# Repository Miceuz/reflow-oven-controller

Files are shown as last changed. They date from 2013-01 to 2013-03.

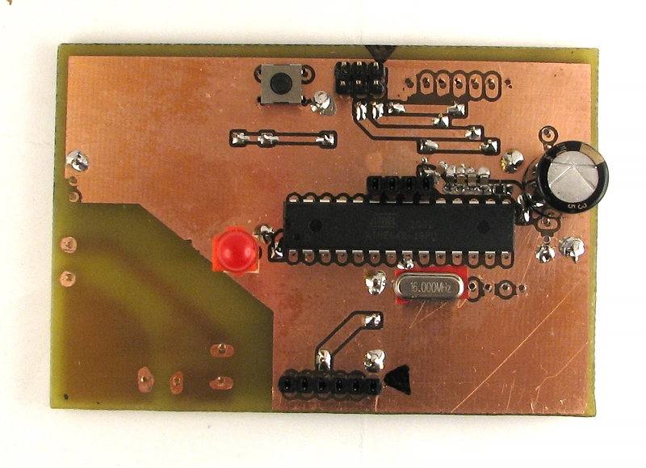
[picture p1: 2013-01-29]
pics/top.jpg

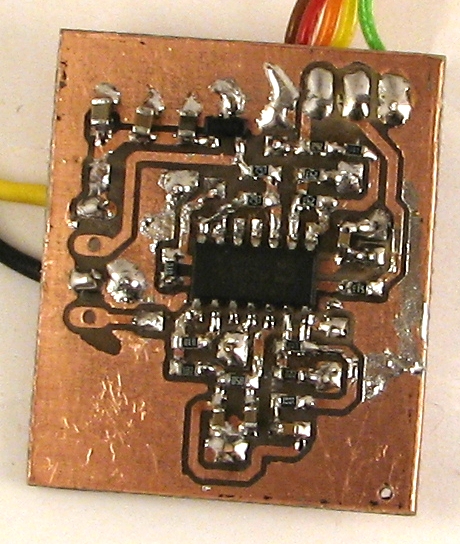
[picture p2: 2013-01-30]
pics/pt100-daughterboard.jpg

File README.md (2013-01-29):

reflow-oven-controller
======================

Yet another reflow oven controller (YAROC, but we called it c-flow) for [c-base](http://c-base.org). The design is mainly based on parts we had available in c-lab. *Note: the project is work in progress, major fuckups may be present in the design files*

The design is modular:
- MCU board has a microcontroller, a solid state relay and a header for analog temperature sensor daughterboards. Headers for ISP programming, SPI communication and CP2102 USB-to-USART module are available too. SSR used is S102S02.
- a daughterboard for PT100 sensor has all the analog sensor conditioning circuitry: constant current source, wire resistance elimination, active filter. Based on Microchip App Note [AN687](http://www.microchip.com/stellent/idcplg?IdcService=SS_GET_PAGE&nodeId=1824&appnote=en011700)
- Arduino compatible

UI features available
---------------------

- power LED
- "heater on" LED
- "oven running" LED
- "start/stop" button
- SPI header for serial LCD module
- I2C header
- 4 AUX IOs with pullup and pulldown pads

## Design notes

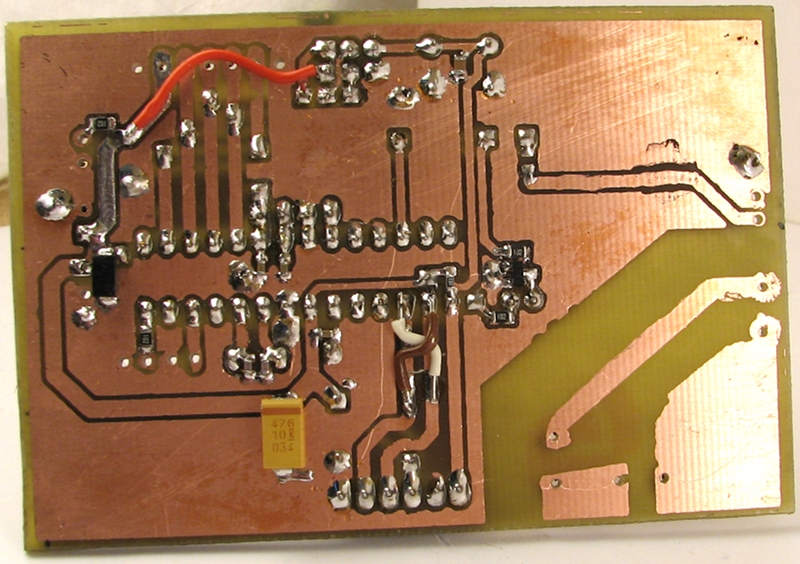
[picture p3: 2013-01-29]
pics/bottom.jpg

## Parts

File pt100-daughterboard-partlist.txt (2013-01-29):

Partlist

Exported from pt100-daughterboard.brd at 2013/01/23/ 4:52 PM

EAGLE Version 5.11.0 Copyright (c) 1988-2010 CadSoft

Part         Value          Package       Library       Position (mm)         Orientation

C1           390nF          C0603         adafruit      (14.605 26.9875)      R90
C2           68nf           C0603         adafruit      (9.525 27.6225)       R180
C3           180nF          C0603         adafruit      (12.3825 26.9875)     R90
C4           10uF           C0805         adafruit      (24.13 6.35)          R270
C5           100nF          C0603         adafruit      (6.35 14.2875)        R270
IC1          LM324D         SO14          linear        (12.7 16.8275)        R0
IC2          REF31XX        DBZ_R-PDSO-G3 mic-misc      (15.24 6.6675)        R180
JP1                         1X03_LONGPADS SparkFun      (3.81 4.1275)         MR180
R1           25K            0603          microbuilder  (8.89 9.8425)         R180
R2           25K            0603          microbuilder  (8.89 11.7475)        R0
R3           25K            0603          microbuilder  (12.7 11.7475)        R180
R4           25K            0603          microbuilder  (12.7 9.8425)         R0
R5           2.5K           0603          microbuilder  (8.89 7.9375)         R180
R6           100K           0603          microbuilder  (18.7325 16.8275)     R270
R7           100K           0603          microbuilder  (16.8275 21.9075)     R180
R9           49.9K          0603          microbuilder  (5.08 17.4625)        R180
R10          17.4K          0603          microbuilder  (16.8275 23.8125)     R0
R11          107K           0603          microbuilder  (13.335 24.4475)      R0
R12          1K             0603          microbuilder  (9.525 25.7175)       R0
R13          3.09K          0603          microbuilder  (9.525 23.8125)       R180
R14          20K            0603          microbuilder  (9.525 21.9075)       R0
SENSOR_BOARD                04P           con-amp-quick (24.13 16.8275)       MR270

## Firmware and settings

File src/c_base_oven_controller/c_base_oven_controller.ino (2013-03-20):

#include <Cmd.h>

#define HEATER A3
#define RUN_LED 8
#define BUTTON 6

#define PRESSED 1
#define MAYBE_PRESSED 2
#define RELEASED 3
#define MAYBE_RELEASED 4

typedef struct {
  byte temperature;
  byte holdSeconds;
} tProgramPoint;

const int tempInput = A0;
boolean heaterOn = false;
boolean running = false;

unsigned long lastPrint = 0;
unsigned long lastDebounce = 0;
byte buttonState = RELEASED;
byte lastButtonState = RELEASED;
//byte setTemperature = 235;
unsigned int tempMaxHold = 30000;
byte tempReached = false;
unsigned long tempReachedTimestamp = 0;

tProgramPoint program[]={
  {150, 180},
  {205, 15},
  {0, 0}
};

byte programStep = 0;


void blinkHello() {
  byte i;
  for(i = 0; i < 10; i++) {
    digitalWrite(RUN_LED, !digitalRead(RUN_LED));
    delay(100);
  }
}

void setup() {
  pinMode(RUN_LED, OUTPUT);
  pinMode(HEATER, OUTPUT);
  pinMode(BUTTON, INPUT);
  digitalWrite(BUTTON, HIGH);//button pullup on
      
  analogReference(EXTERNAL);
  cmdInit(9600);
  
  cmdAdd("stop", stopit);
  cmdAdd("run", run);
  cmdAdd("setTemp", setTemp);
  blinkHello();
  Serial.println("Hello");
}

void loop() {
  cmdPoll();

  if(buttonPress()) {
    if(running) {
      stopit(0, 0);
    } else {
      run(0, 0);
    }
  }

  int sensorValue = analogRead(tempInput);
  int resistance = (float) map(sensorValue, 0, 1023, 0, 250000) / (float)11 * 1.007 + 60.296;// * 1.041 - 597.6;
  float temperature = (resistance - 10000)/38.5;
    
  if(heaterOn) {
    digitalWrite(HEATER, HIGH);
  } else {
    digitalWrite(HEATER, LOW);
  }

  if(running) {
    digitalWrite(RUN_LED, HIGH);
    if(temperature < program[programStep].temperature) {
      heaterOn = true;
    } else {
      heaterOn = false;
      if(!tempReached) {
        tempReached = true;
        tempReachedTimestamp = millis();
      }
    }
    if(tempReached) {
      if((millis() - tempReachedTimestamp)/1000 > program[programStep].holdSeconds) {
        programStep ++;
        Serial.print("next temp:");
        Serial.println(program[programStep].temperature);
        if(0 == program[programStep].temperature) {
          Serial.println("Stopping");
          stopit(0, 0);
        } else {
          tempReached = false;
        }
      }
    }
  } else {
    digitalWrite(RUN_LED, LOW);
  }
  
  if(millis() - lastPrint > 1000) {
    Serial.println(temperature);
    lastPrint = millis();
  }
}

void run(int argc, char** argv) {
  programStep = 0;
  heaterOn = true;
  running = true;
  tempReached = false;  
}

void stopit(int argc, char** argv) {
  heaterOn = false;
  running = false;
}

void setTemp(int argc, char** argv) {
  if(2 == argc) {
    program[programStep].temperature = atol(argv[1]);
    Serial.print("Setting to ");
    Serial.println(program[programStep].temperature);
  } else {
    Serial.println("Usage: setTemp <temperature>");
  }
}

boolean buttonPress() {
  byte button = digitalRead(BUTTON);
  switch(buttonState) {
    case MAYBE_PRESSED:
      delay(100);
      if(LOW == button) {
        buttonState = PRESSED;
      } else {
        buttonState = RELEASED;
      }
      break;
    case PRESSED:
      if(HIGH == button) {
        buttonState = MAYBE_RELEASED;
      }
      break;
    case MAYBE_RELEASED:
      delay(100);
      if(HIGH == button) {
        buttonState = RELEASED;
      } else {
        buttonState = PRESSED;
      }
      break;
    case RELEASED:
      if(LOW == button) {
        buttonState = MAYBE_PRESSED;
      }
      break;
  }
  boolean ret = lastButtonState != buttonState && PRESSED == buttonState;
  lastButtonState = buttonState;

  return ret;
}

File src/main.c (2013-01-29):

#include <avr/io.h>
#include <util/delay.h>
#include <stdio.h>
#include "LiquidCrystal.h"

static int uart_putchar(char c, FILE *stream);
static FILE mystdout = FDEV_SETUP_STREAM(uart_putchar, NULL, _FDEV_SETUP_WRITE);
static int lcd_putchar(char c, FILE *stream);
static FILE lcd = FDEV_SETUP_STREAM(lcd_putchar, NULL, _FDEV_SETUP_WRITE);

static int uart_putchar(char c, FILE *stream) {
  if (c == '\n') {
    uart_putchar('\r', stream);
  }
  loop_until_bit_is_set(UCSRA, UDRE);
  UDR = c;
  return 0;
}

static int lcd_putchar(char c, FILE *stream) {
  LCDwrite(c);
  return 0;
}

void uart_init(void) {
  #define BAUD 9600
  #include <util/setbaud.h>
  UBRRH = UBRRH_VALUE;
  UBRRL = UBRRL_VALUE;
  
#if USE_2X
  UCSRA |= _BV(U2X);
#else
  UCSRA &= ~(_BV(U2X));
#endif
  
  UCSRC = _BV(URSEL) | _BV(UCSZ1) | _BV(UCSZ0); /* 8-bit data */ 
  UCSRB = _BV(RXEN) | _BV(TXEN);   /* Enable RX and TX */
}

int main (void) {
  DDRC |= _BV(PC3);
  uart_init();
  stdout = &mystdout;

  LiquidCrystal();
  LCDbegin(8, 2);
  
//  fputs("GRIBAS", &lcd);
  fprintf(&lcd, "GRIB");
  uint16_t c = 0;
  while(1) {
    PORTC |= _BV(PC3);
    _delay_ms(500);
    PORTC &= ~_BV(PC3);
    _delay_ms(500);
    puts("Hello, world!\n");
    LCDsetCursor(0,1);
    fprintf(&lcd, "%d", c++);
  }
}

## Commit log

2013-01-21 Innitial commit
    [oven-controller.brd, oven-controller.sch]
2013-01-22 left atmega8 board as simple avr board, made a separate daugher board for PT100 sensor
    [oven-controller.brd, oven-controller.sch, pt100-daughterboard.brd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]
2013-01-23 basic blinking led/hello world firmware for testing
2013-01-23 some photos of controller board
2013-01-27 some fixes after soldering the first prototype - some resistor values combined from several resistors, gain setting resistors changed
    [pt100-daughterboard.brd, pt100-daughterboard.sch]
2013-01-27 some comments to schematics
    [pt100-daughterboard.sch]
2013-01-27 add a cap on reference output
    [pt100-daughterboard.brd, pt100-daughterboard.sch]
2013-01-27 A port of Arduino LiquitCrystal LCD library altered by Adafruit for 74hc595 based serial interface to LCD
2013-01-28 moving to arduino codebase, error correction coeficints
    [Cmd.cpp, c_base_oven_controller.ino, cmd_line_ex1_hello.pde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]
2013-01-29 Added i2c port, fuseholder, 4 aux pins I hope this can be rendered, since there are some low distance paths, esp. near i2c
    [oven-controller.brd, oven-controller.sch]
2013-01-30 * rx, tx pins swapped * pullups on rx, tx pins help avoid noise pickup during arduino bootloader timeout
    [oven-controller.brd, oven-controller.sch]
2013-03-20 temperature profile set up expermentally
